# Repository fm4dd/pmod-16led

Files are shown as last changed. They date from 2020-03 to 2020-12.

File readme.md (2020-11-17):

## 16LED PMOD

### Description

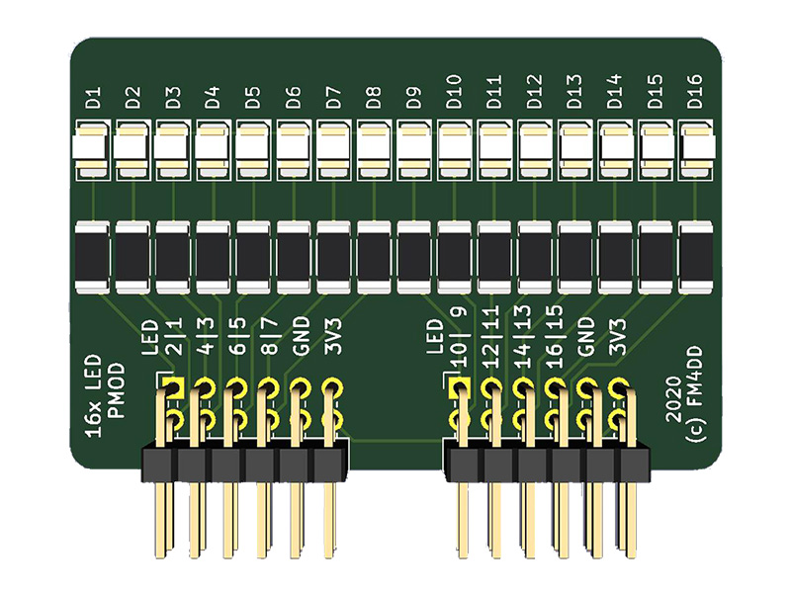
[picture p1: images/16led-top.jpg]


This PMOD provides a sixteen LED display output to FPGA designs via two double-row PMODs.
[fpga.fm4dd.com](http://fpga.fm4dd.com)

### Schematic

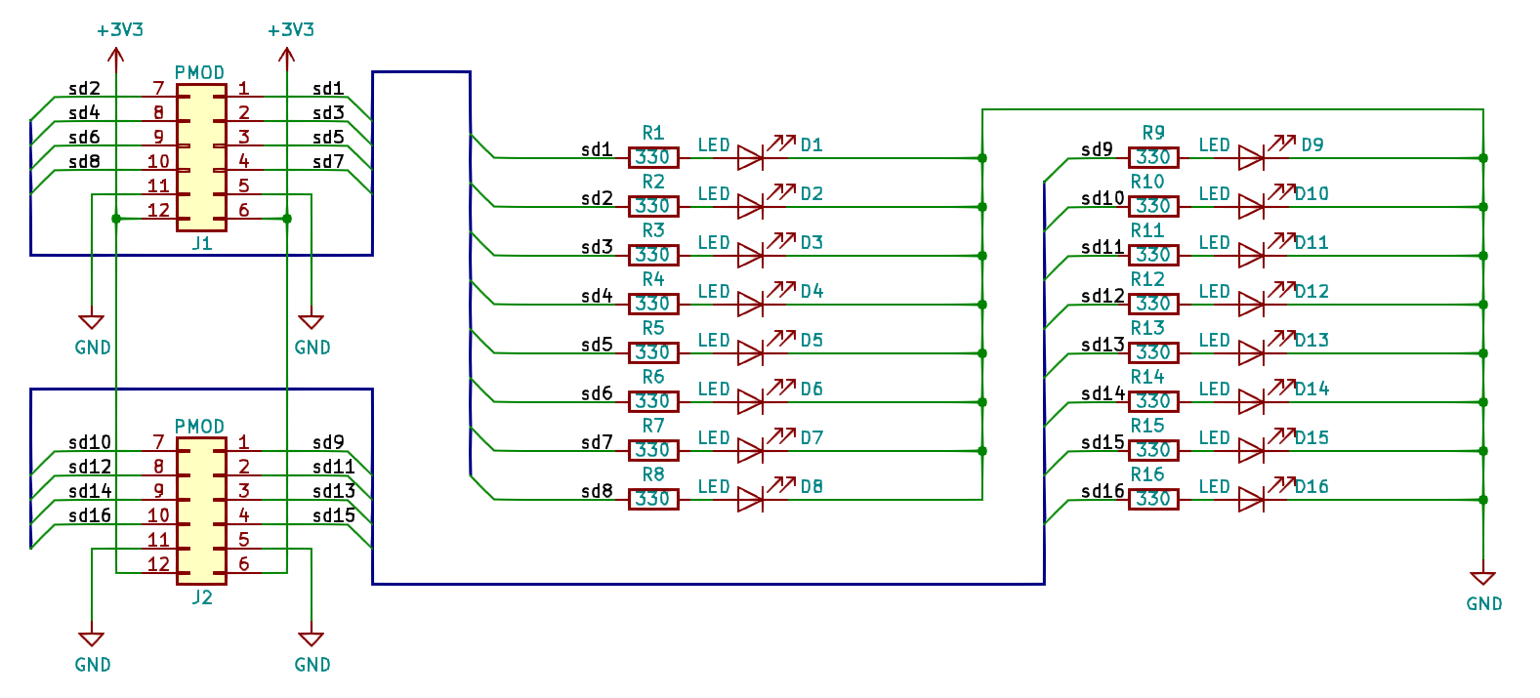
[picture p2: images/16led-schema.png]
16LED PMOD Schematics


### Pin Assignments

#### IceBreaker v1.0

 J1# |  Label | Description   | PMOD1A
-----|--------|---------------|-------
1    |  D1    | LED D1        | 4
7    |  D2    | LED D2        | 3
2    |  D3    | LED D3        | 2
8    |  D4    | LED D4        | 48
3    |  D5    | LED D5        | 47
9    |  D6    | LED D6        | 46
4    |  D7    | LED D7        | 45
10   |  D8    | LED D8        | 44

 J2# |  Label | Description   | PMOD1B
-----|--------|---------------|-------
1    |  D9    | LED D9        | 43
7    |  D10   | LED D10       | 42
2    |  D11   | LED D11       | 38
8    |  D12   | LED D12       | 36
3    |  D13   | LED D13       | 44
9    |  D14   | LED D14       | 32
4    |  D15   | LED D15       | 31
10   |  D16   | LED D16       | 28

#### DE0-Nano-SoC

 J1# |  Label | Description   | GPIO0A | GPIO1A
-----|--------|---------------|--------|--------
1    |  D2    | LED D1        | PIN_AF8|PIN_AH27
2    |  D1    | LED D2        | PIN_W12|PIN_AA15
3    |  D4    | LED D3        | PIN_AB4|PIN_AH24
4    |  D3    | LED D4        | PIN_Y8 |PIN_AG26
7    |  D6    | LED D5        | PIN_Y4 |PIN_AE22
8    |  D5    | LED D6        | PIN_W8 |PIN_AF23
9    |  D8    | LED D7        | PIN_U11|PIN_AG20
10   |  D7    | LED D8        | PIN_Y5 |PIN_AF21

 J2# |  Label | Description   | GPIO0B | GPIO1B
-----|--------|---------------|--------|--------
1    |  D13   | LED D13       | PIN_AG6| PIN_AD19
2    |  D9    | LED D9        | PIN_AF4| PIN_AH23
3    |  D14   | LED D14       | PIN_AE4| PIN_AE20
4    |  D10   | LED D10       | PIN_AF5| PIN_AG23
7    |  D15   | LED D15       | PIN_T11| PIN_AE24
8    |  D11   | LED D11       | PIN_T13| PIN_AE19
9    |  D16   | LED D16       | PIN_AF6| PIN_AD20
10   |  D12   | LED D12       | PIN_AE7| PIN_AF18

### Example Code

#### Verilog

Verilog test program pmod16led_1.v (top-level):
```
// -------------------------------------------------------
// This program is a binary counter displayed on the
// on the pmod D2-8, and 9-16. D1 is pulsing 1Hz clock.
// 12MHz clock: set breakpoint at 23'd5999999
// 50MHz clock: set breakpoint at 25'd24999999
// -------------------------------------------------------
module pmod16led_1 (
  input clk,
  output reg [0:7] pmodled1,
  output reg [0:7] pmodled2,
);

  reg [22:0] count = 23'd0;
  reg clk_1hz = 1'b0;
  assign pmodled1[0] = clk_1hz;

  reg [6:0] lednum1 = 7'd0;
  assign pmodled1[7:1] = lednum1;

  reg [7:0] lednum2 = 8'd0;
  assign pmodled2[7:0] = lednum2;

  always @(posedge clk)
  begin
    count   <= count + 1;
    if(count == 23'd5999999)
    begin
      count   <= 0;
      clk_1hz <= ~clk_1hz;
      lednum1 <= lednum1 + 1;
      lednum2 <= lednum2 + 1;
    end
  end
endmodule
```
#### VHDL

This is Verilog test program pmod16led_1.v converted to VHDL as pmod16led_2.vhd

```
library ieee;
use ieee.std_logic_1164.all;
use ieee.numeric_std.all;

entity pmod_16led_2 is
port (
       clk: in STD_LOGIC;
  pmodled1: out STD_LOGIC_VECTOR(0 to 7) := "00000000";
  pmodled2: out STD_LOGIC_VECTOR(0 to 7) := "00000000"
);
end pmod_16led_2;

architecture arch of pmod_16led_2 is
  signal clk_1hz: STD_LOGIC := '0';
  signal  lednum1: STD_LOGIC_VECTOR(6 downto 0) := "0000000";
  signal  lednum2: STD_LOGIC_VECTOR(7 downto 0) := "00000000";

  begin
    counter_p: process( clk, clk_1hz, lednum1, lednum2 )
    variable count: INTEGER := 0;
    begin
      if( rising_edge(clk) ) then
        count := count + 1;
        if( count = 24999999 ) then
          count := 0;
          clk_1hz <= NOT clk_1hz;
          lednum1 <= std_logic_vector( unsigned(lednum1) + 1);
          lednum2 <= std_logic_vector( unsigned(lednum2) + 1);
        end if;
      end if;

    pmodled1(0) <= clk_1hz;
    pmodled1(1) <= lednum1(6);
    pmodled1(2) <= lednum1(5);
    pmodled1(3) <= lednum1(4);
    pmodled1(4) <= lednum1(3);
    pmodled1(5) <= lednum1(2);
    pmodled1(6) <= lednum1(1);
    pmodled1(7) <= lednum1(0);

    pmodled2 <= lednum2;
  end process counter_p;
end arch;
```
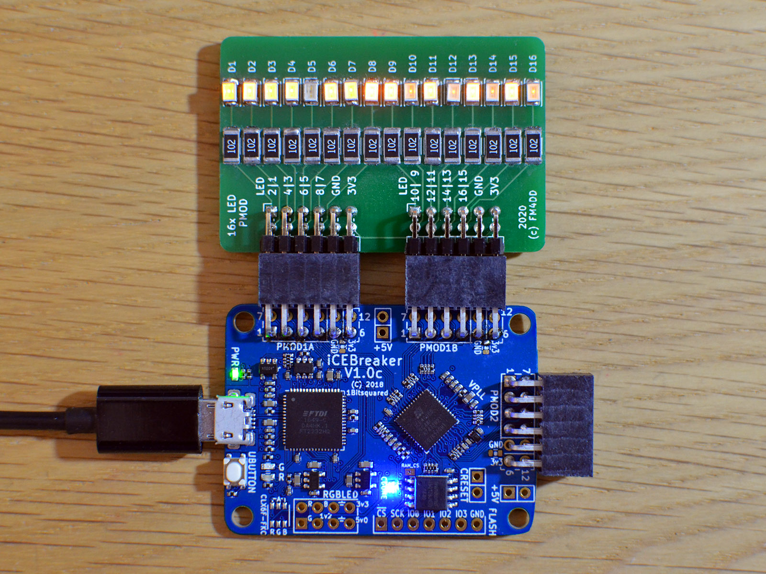
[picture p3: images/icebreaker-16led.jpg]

16LED Pmod on a iceBreaker board

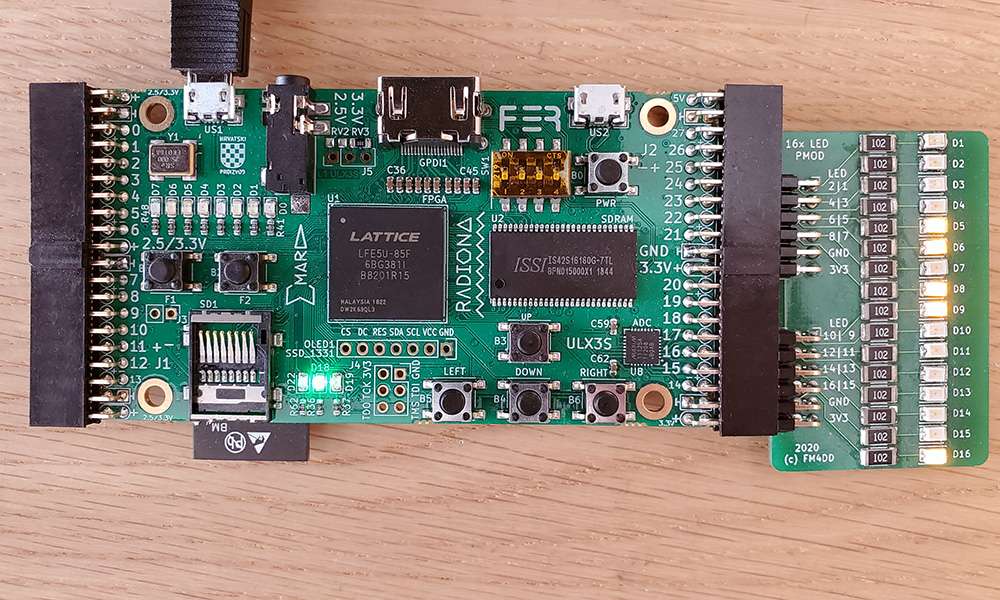
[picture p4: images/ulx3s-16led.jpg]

16LED Pmod on a 85K ULX3S board

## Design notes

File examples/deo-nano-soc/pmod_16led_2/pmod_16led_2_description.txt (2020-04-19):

This program is demonstrating the function of the 16LED PMOD under VHDL.  It implements a binary counter displayed on the pmod D2-8, and D9-16. D1 is pulsing a derived 1Hz clock. 

The functionality has been converted from the Verilog program pmod_16led_1.v, tested on a Icebreaker v1.0 board, using the Linux open source workflow (yosys, nextpnr, and icestorm). Without an open source VHDL workflow, I am testing VHDL on a DE0-Nano-SoC board with Quartus Prime Version 17.1 Lite Edition on Windows.

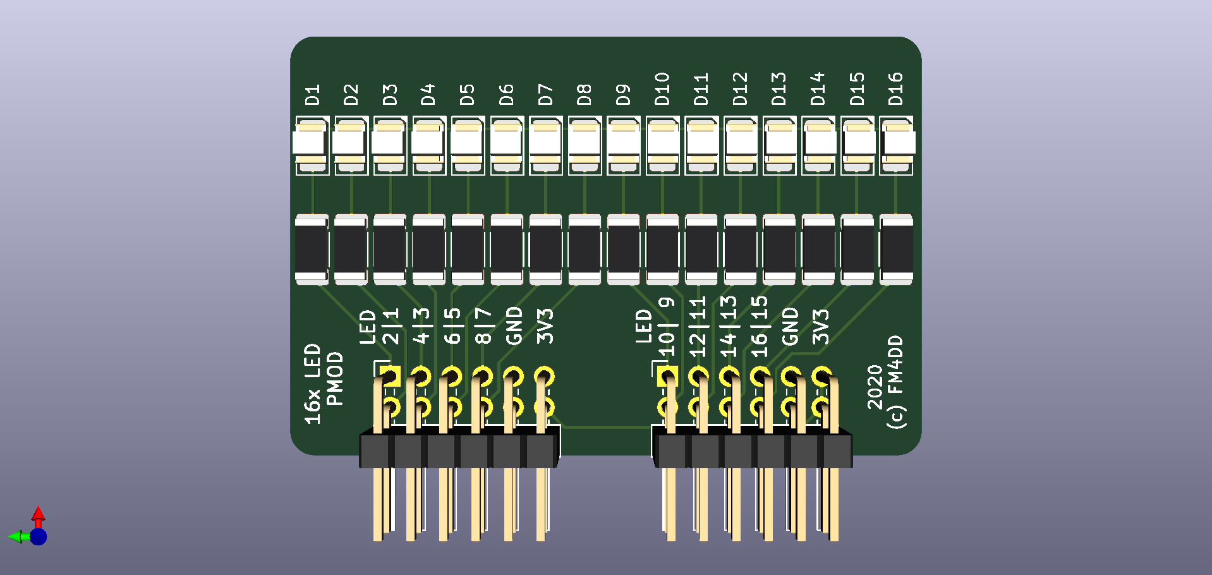
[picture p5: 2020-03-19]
images/pmod-16led.png

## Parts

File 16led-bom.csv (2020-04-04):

Manufacturer Part Number | Manufacturer | Digi-Key Part Number | Reference | Quantity | Description
RMCF2010JT1K20 | Stackpole Electronics Inc | RMCF2010JT1K20CT-ND | R1-16 | 16 | 1K2 RESISTOR SMD 2010 (5025 Metric) see LED type
RC2010JK-07220RL | Yageo | YAG3386CT-ND | R1-16 | 16 | 220 RESISTOR SMD 2010 (5025 Metric) see LED type
SML-012WT | Rohm Semiconductor | N/A, alternate below | D1-D16 | 16 | LED YELLOW CLEAR SMD 1208 (3020) 280mcd = 1K resistor
5973401507F | Dialight | 350-2435-1-ND | D1-D16 | 16 | LED YELLOW CLEAR SMD 1208 (3020) 6.3mcd = 220 resistor
PEC20DBAN | Sullins Connector Solutions | S2112E-20-ND | J1,J2 | 1 | CONN HEADER R/A 40POS 2.54MM cut to size

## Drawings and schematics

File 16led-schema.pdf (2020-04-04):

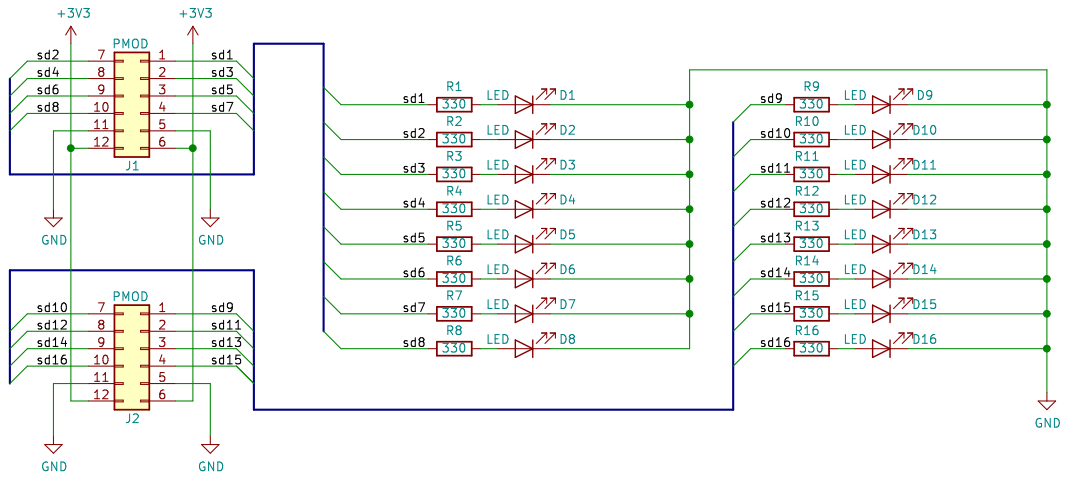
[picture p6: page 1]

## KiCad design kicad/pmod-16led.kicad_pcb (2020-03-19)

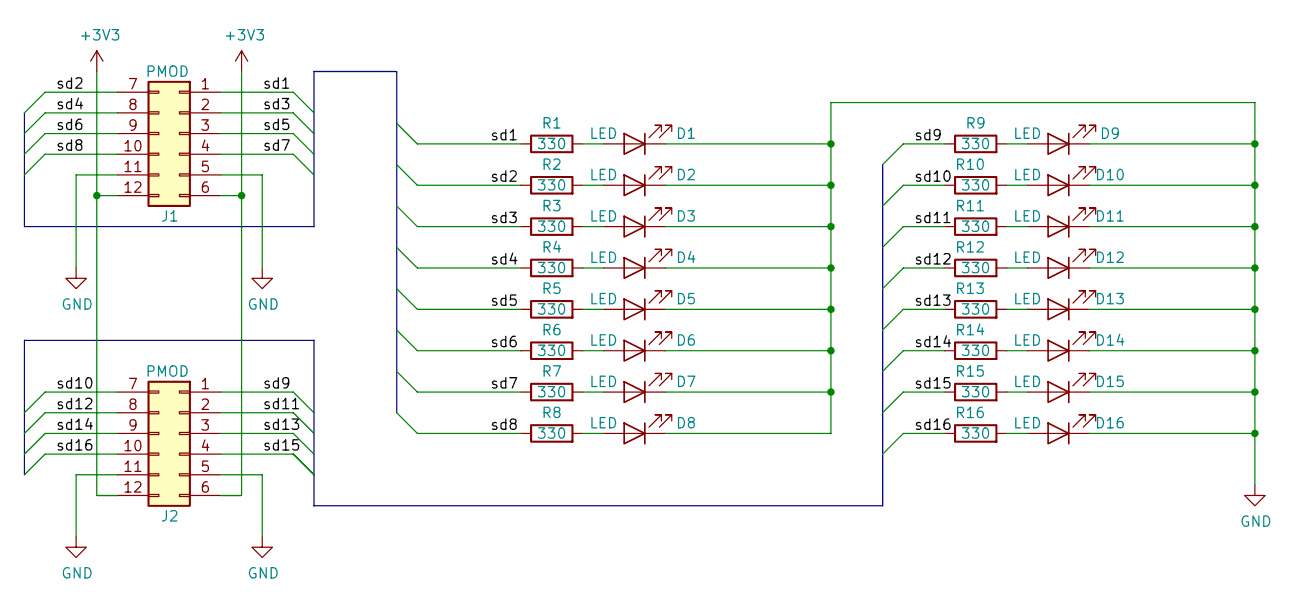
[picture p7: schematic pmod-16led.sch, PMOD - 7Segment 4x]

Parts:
D1, D2, D3, D4, D5, D6, D7, D8, D9, D10, D11, D12, D13, D14, D15, D16: LED; LED_3020Metric_Pad1.42x2.65mm_HandSolder
J1, J2: PMOD; PMODHeader_2x06_P2.54mm_Horizontal
R1, R2, R3, R4, R5, R6, R7, R8, R9, R10, R11, R12, R13, R14, R15, R16: 330; R_2010_5025Metric

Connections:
+3V3: J1.6, J1.12, J2.6, J2.12
/sd1: J1.1, R1.1
/sd2: J1.7, R2.1
/sd3: J1.2, R3.1
/sd4: J1.8, R4.1
/sd5: J1.3, R5.1
/sd6: J1.9, R6.1
/sd7: J1.4, R7.1
/sd8: J1.10, R8.1
/sd9: J2.1, R9.1
/sd10: J2.7, R10.1
/sd11: J2.2, R11.1
/sd12: J2.8, R12.1
/sd13: J2.3, R13.1
/sd14: J2.9, R14.1
/sd15: J2.4, R15.1
/sd16: J2.10, R16.1
GND: D1.1 (K), D2.1 (K), D3.1 (K), D4.1 (K), D5.1 (K), D6.1 (K), D7.1 (K), D8.1 (K), D9.1 (K), D10.1 (K), D11.1 (K), D12.1 (K), D13.1 (K), D14.1 (K), D15.1 (K), D16.1 (K), J1.5, J1.11, J2.5, J2.11
unnamed: D1.2 (A), R1.2
unnamed: D2.2 (A), R2.2
unnamed: D3.2 (A), R3.2
unnamed: D4.2 (A), R4.2
unnamed: D5.2 (A), R5.2
unnamed: D6.2 (A), R6.2
unnamed: D7.2 (A), R7.2
unnamed: D8.2 (A), R8.2
unnamed: D9.2 (A), R9.2
unnamed: D10.2 (A), R10.2
unnamed: D11.2 (A), R11.2
unnamed: D12.2 (A), R12.2
unnamed: D13.2 (A), R13.2
unnamed: D14.2 (A), R14.2
unnamed: D15.2 (A), R15.2
unnamed: D16.2 (A), R16.2

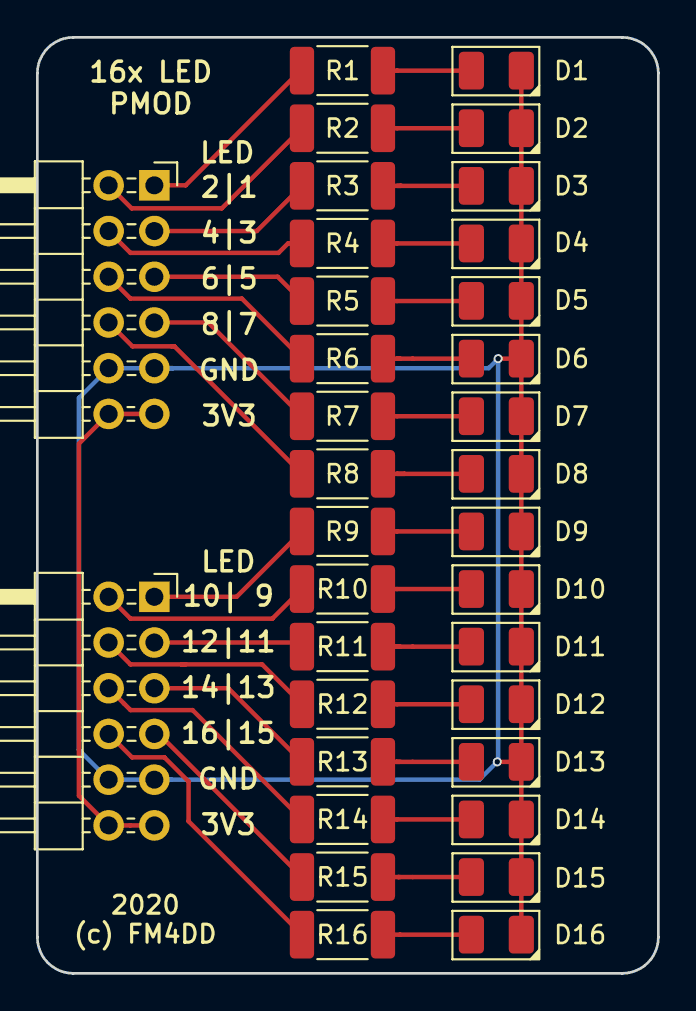
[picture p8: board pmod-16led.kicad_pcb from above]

Board: 2 copper layers, 34.5 x 52.0 mm, 34 parts (0 on the bottom side), 34 nets.

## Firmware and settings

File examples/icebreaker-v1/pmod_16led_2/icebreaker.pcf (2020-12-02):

# 12 MHz clock
set_io -nowarn clk        35

# RS232
set_io -nowarn RX          6
set_io -nowarn TX          9

# LEDs and Button
set_io -nowarn BTN_N      10
set_io -nowarn LEDR_N     11
set_io -nowarn LEDG_N     37

# RGB LED Driver
set_io -nowarn LED_RED_N  39
set_io -nowarn LED_GRN_N  40
set_io -nowarn LED_BLU_N  41

# SPI Flash
set_io -nowarn FLASH_SCK  15
set_io -nowarn FLASH_SSB  16
set_io -nowarn FLASH_IO0  14
set_io -nowarn FLASH_IO1  17
set_io -nowarn FLASH_IO2  12
set_io -nowarn FLASH_IO3  13

# PMOD 1A
#set_io -nowarn P1A1        4
#set_io -nowarn P1A2        2
#set_io -nowarn P1A3       47
#set_io -nowarn P1A4       45
#set_io -nowarn P1A7        3
#set_io -nowarn P1A8       48
#set_io -nowarn P1A9       46
#set_io -nowarn P1A10      44
set_io -nowarn pmodled[0]  4
set_io -nowarn pmodled[1]  3
set_io -nowarn pmodled[2]  2
set_io -nowarn pmodled[3] 48
set_io -nowarn pmodled[4] 47
set_io -nowarn pmodled[5] 46
set_io -nowarn pmodled[6] 45
set_io -nowarn pmodled[7] 44

# PMOD 1B
#set_io -nowarn P1B1       43
#set_io -nowarn P1B2       38
#set_io -nowarn P1B3       34
#set_io -nowarn P1B4       31
#set_io -nowarn P1B7       42
#set_io -nowarn P1B8       36
#set_io -nowarn P1B9       32
#set_io -nowarn P1B10      28
set_io -nowarn pmodled[8]  43
set_io -nowarn pmodled[9]  42
set_io -nowarn pmodled[10] 38
set_io -nowarn pmodled[11] 36
set_io -nowarn pmodled[12] 34
set_io -nowarn pmodled[13] 32
set_io -nowarn pmodled[14] 31
set_io -nowarn pmodled[15] 28

# PMOD 2
set_io -nowarn P2_1       27
set_io -nowarn P2_2       25
set_io -nowarn P2_3       21
set_io -nowarn P2_4       19
set_io -nowarn P2_7       26
set_io -nowarn P2_8       23
set_io -nowarn P2_9       20
set_io -nowarn P2_10      18

# LEDs and Buttons (PMOD 2)
set_io -nowarn LED[0]      26
set_io -nowarn LED[1]      27
set_io -nowarn LED[2]      25
set_io -nowarn LED[3]      23
set_io -nowarn LED[4]      21
set_io -nowarn SW[0]      20
set_io -nowarn SW[1]      19
set_io -nowarn SW[2]      18

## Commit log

2020-03-20 verilog and pin # update
2020-04-02 fix pin assignment and add VHDL example
2020-04-04 update schema, add BOM
    [pmod-16led.sch]

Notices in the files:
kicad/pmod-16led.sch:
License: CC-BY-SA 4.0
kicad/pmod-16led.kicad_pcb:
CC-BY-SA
